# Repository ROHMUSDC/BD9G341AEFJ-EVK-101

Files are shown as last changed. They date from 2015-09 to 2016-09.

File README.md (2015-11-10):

# BD9G341AEFJ-EVK-101 Design Resource Repository
* Hardware Design Files and Documentation for the ROHM BD9G341AEFJ-EVK-101 EVK

----
### Description: 
* The BD9G341AEFJ is a buck switching regulator with integrated 150m Ω power MOSFET
* Current mode architecture provides fast transient response and a simple phase compensation setup
* The operating frequency is programmable from 50kHz to 750kHz
* Over current protection, thermal shutdown and under voltage lockout are also included with the IC
* The under voltage lockout and hysteresis can be set by external resistor

----
### Repository Contents
* Design Files: Contains Board, Gerber, Schematic, and BOM information for this EVK Board
* Measurement Reports Folder: Contains measurement testing information completed for these EVK Boards
* RoHS Compliance Folder: Contained RoHS Specific BOM and references to CoCs for parts on this board
* User's Guide: Contains the User Guide for this EVK

----
### Where to Purchase?
* http://www.rohm.com/web/global/distribution/-/dinventory/BD9G341AEFJ-E2/sample/0

----
### DISCLAIMER
This Technical Data is protected under copyright laws.

ROHM hereby grants you a nonexclusive, nontransferable license to use this Technical Data 
as long as you abide by the terms and conditions of this DISCLAIMER. 

However, you are not authorized to sell, loan, rent, lease, redistribute or license this Technical Data, 
in whole or in part, or in modified form, to anyone.

You may modify this Technical Data to suit your specific applications, 
but the rights to derivative works and said modifications shall belong to ROHM. 

You may make copies of this Technical Data as necessary for internal use only within your company.

In any case, the latest datasheet is considered the final design guideline and represents 
the only actual performance specifications.

ROHM shall not be responsible for ensuring proper application on all computer systems.
This Technical Data is provided AS IS. ROHM makes no guarantees, either implicitly or explicitly, 
regarding its usability, functionality, accuracy, merchantability, or fitness for a specific purpose.

In addition, you shall take full responsibility for the use of any information acquired from this Technical Data. 

ROHM does not assume warranty of any kind arising from the use of this Technical Data. ACCORDINGLY, 
IN NO EVENT SHALL ROHM BE RESPONSIBLE, WHETHER THROUGH CONTRACT OR TORT LIABILITY, 
FOR ANY DAMAGES (INCLUDING BUT NOT LIMITED TO LOST PROFITS OR OTHER INCIDENTAL, CONSEQUENTAL, 
OR PUNITIVE DAMAGES) ARISING OUT OF OR IN CONNECTION WITH THE USE OR APPLICATION OF THIS Technical Data.

Furthermore, this Technical Data is subject to change without notice.

Unless otherwise expressly provided herein, ROHM does not convey any license under patent rights 
or any other intellectual property rights (including those of third parties).

ROHM is not obligated to provide maintenance or support for the Technical Data.

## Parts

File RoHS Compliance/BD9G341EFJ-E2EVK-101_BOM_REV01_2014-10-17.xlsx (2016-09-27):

BD9G341EFJ-E2EVK-101 |  |  | FAB/ASSY RoHS Certificate of Compliance: |  | FAB-9_FAB-ASSY_RoHS Cert.pdf
Revision: 0.1
Bill Of Materials
Item | Quantity | Reference | Part | PCB Footprint | DESCRIPTION | MFG1 | MFG1_PART# | DISTR1 | DISTR1_PART# | DNP | Provided by ROHM | ROHM Comment
1 | 1 | C1 | 10uF | C2421 | CAP CER 10UF 100V 20% X7R SMD | Murata Electronics North America | KRM55TR72A106MH01K | Digi-Key | 490-5783-2-ND |  | Y | Murata_CO2E_100112-558472.pdf
2 | 1 | C3 | 6800pF | C0603 | CAP CER 6800PF 50V 10% X7R 0603 | Murata Electronics North America | GRM188R71H682KA01D | Digi-Key | 490-1508-2-ND |  | Y | Murata_CO2E_100112-558472.pdf
3 | 1 | C4 | 0.1uF | C0603 | CAP CER 0.1UF 50V 10% X7R 0603 | Murata Electronics North America | GRM188R71H104KA93D | Digi-Key | 490-1519-2-ND |  | Y | Murata_CO2E_100112-558472.pdf
4 | 1 | C5 | 100uF | C1206 | CAP CER 100UF 6.3V 20% X5R 1206 | Murata Electronics North America | GRM31CR60J107ME39L | Digi-Key | 490-4539-2-ND |  | Y | Murata_CO2E_100112-558472.pdf
5 | 1 | D2 | RB095B-90TL | SC-63 | DIODE SCHOTTKY 90V 3A CPD | Rohm | RB095B-90TL | Digi-Key | RB095B-90TLTR-ND |  | Y | RoHS Compliance Letter_20131212.pdf
6 | 1 | J1 | 68000-103HLF | HDR_THVT_1X3_100 | CONN HEADER VERT .100 3POS 15AU | FCI | 68000-103HLF | DIGIKEY | 609-3461-ND |  | N | FCICOC68000-103HLF.pdf
7 | 1 | L1 | 33uH | IND-4747-SMD | INDUCTOR POWER 33UH 4.2A SMD | Wurth Electronics Inc | 7447709330 | Digi-Key | 732-1244-2-ND |  | Y | WurthRoHS.pdf
8 | 1 | R1 | 110k | R0603 | RES 110K OHM 1/10W 1% 0603 SMD | Rohm | MCR03ERTF1103 | Digi-Key | RHM110KCFTR-ND |  | Y | RoHS Compliance Letter_20131212.pdf
9 | 1 | R2 | 27k | R0603 | RES 27K OHM 1/10W 1% 0603 SMD | Rohm | MCR03ERTF2702 | Digi-Key | RHM27.0KCFTR-ND |  | Y | RoHS Compliance Letter_20131212.pdf
10 | 1 | R3 | 10k | R0603 | RES 10K OHM 1/10W 1% 0603 SMD | Rohm | MCR03ERTF1002 | Digi-Key | RHM10.0KCFTR-ND |  | Y | RoHS Compliance Letter_20131212.pdf
11 | 1 | R4 | 47k | R0603 | RES 47K OHM 1/10W 1% 0603 SMD | Rohm | MCR03ERTF4702 | Digi-Key | RHM47.0KCFTR-ND |  | Y | RoHS Compliance Letter_20131212.pdf
12 | 1 | R5 | 3k | R0603 | RES 3K OHM 1/10W 1% 0603 SMD | Rohm | MCR03ERTF3001 | Digi-Key | RHM3.00KCFTR-ND |  | Y | RoHS Compliance Letter_20131212.pdf
13 | 1 | R6 | 750 | R0603 | RES 750 OHM 1/10W 1% 0603 SMD | Rohm | MCR03ERTF7500 | Digi-Key | RHM750CFTR-ND |  | Y | RoHS Compliance Letter_20131212.pdf
14 | 2 | TP1,TP3 | TP_TH_63MIL_RED | TP_TH | TEST POINT PC MULTI PURPOSE RED | Keystone Electronics | 5010 | Digi-Key | 5010K-ND |  | N | KeystoneRoHS.pdf
15 | 2 | TP2,TP4 | TP_TH_63MIL_BLK | TP_TH | TEST POINT PC MULTI PURPOSE BLK | Keystone Electronics | 5011 | Digi-Key | 5011K-ND |  | N | KeystoneRoHS.pdf
16 | 1 | U1 | BD9G341EFJ | HTSOP-J8 | IC REG BUCK SYNC ADJ 3A HTSOP-J8 |  |  |  |  |  | Y
17 | 1 |  |  |  | Shunt jumper for header J1(item #6), CONN SHUNT 2POS GOLD W/HANDLE | TE Connectivity | 881545-1 | Digi-Key | 881545-1-ND |  | N | TE_RoHS.pdf
18 | 2 | C2,C7 | TBD | C0603 |  |  |  |  |  | Do Not Place
19 | 1 | C6 | TBD | C1210 |  |  |  |  |  | Do Not Place
20 | 1 | D1 | TBD | DO-214AB |  |  |  |  |  | Do Not Place

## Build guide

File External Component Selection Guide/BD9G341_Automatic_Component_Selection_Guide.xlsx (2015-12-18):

How to Use this Selector Guide: 1. Fill in the constants that are highlighted yellow in column B 2. Change External components in Green Font to meet the optimized characteristics 3. Refer to User Manual and Schematic for any additional questions on why these values are set as they are.
Please refer to the schematic found in the GitHub Repository at the following location: ...BD9G341AEFJ-EVK-101/Design Files/Schematic_BOM/BD9G341EFJ-E2EVK-101_SCH_REV01_2014-10-17.pdf
Please refer to the user's guide found in the GitHub repository at the following location for explanation on the calculations completed in this document: ...BD9G341AEFJ-EVK-101/User's Guide/BD9G341AEFJ-EVK-101_EVK_UsersGuide_REV03_E_151027.pdf
BD9G341 Components Selection
Vcc (V) | 40
Vout (V) | 10
Inductor (uH) : L1 | 33
Switching Frequency (kHz) | 400
Output Ripple Current (mA) | 0.5681818182
Pull-up Feedback Resistor (kOhms) : R1 | 18
Pull-down feedback Resistor (kOhms) : R2 | 2
Cout (uF) | 100
ESR[Cout] (mOhms) | 0.1
Output Ripple Voltage (mV) | 2.317541805
Iout (mA) | 3000
Maximum Input Ripple Voltage (mV) | 50
CVCC (uF) : C1 | 10
Input Ripple Voltage (mV) | 140.625
Input Ripple Current (A) | 1.299038106
Maximum Input Ripple Current (A) | 1.5
Compensation Resistor (ohms) : R3 | 41887.90205
Compensation Capacitor (nF) : C3 > | 0.7599088773
Second Phase Compensation (uF) : C8 | 0
Under-voltage lockout threshold (V) | 9
UVLO Hysterisys (V) | 0.9
Enable Resistor Network (Pull-Up) (Kohms) : R5 | 90
Enable Resistor Network (Pull-Down) (Kohms) : R6 | 36.5625
Oscillation Resistance (kOhms) : R4 | 21.76616915
Maximum Duty Cycle | 0.8
Maximum output Voltage | 31.9325

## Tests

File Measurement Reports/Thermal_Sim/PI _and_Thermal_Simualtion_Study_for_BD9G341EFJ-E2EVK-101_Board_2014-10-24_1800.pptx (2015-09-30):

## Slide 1

PI and Thermal Simulation Study for BD9G341EFJ Board
October 24th, 2014
Hosted by: Xuan Dang/Chuong Ngo

PTH Solutions Confidential

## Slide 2

Agenda
  I. Introduction
  II. DC Drop Analysis
  III. Current Density Analysis
  IV. Thermal Analysis
  V. Conclusion

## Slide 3

Introduction

1. This work considers power simulation and thermal simulation on BD9G341EFJ boards.
  - Based on board file BD9G341EFJ-E2EVK-101_BRD_REV00_2014-10-17_1800.brd
2. PowerDC software is used for simulation
3. PI simulation considers:
  a. DC Drop analysis
    - Determine what the max drop for power rail
  b. Current Density analysis
    - Determine the hot spot of current density on PCB
4. Thermal simulation considers:
    - PCB temperature profile including consideration for conductive, radiative, and convective heat transfer

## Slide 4

BD9G341EFJ Board

- Based on the board file : BD9G341EFJ-E2EVK-101_BRD_REV00_2014-10-17_1800.brd

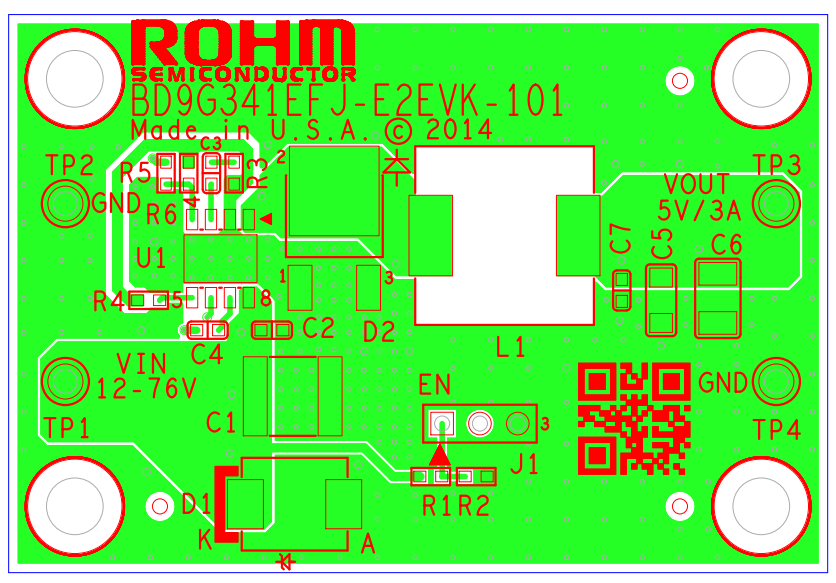
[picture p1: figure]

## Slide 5

BD9G341EFJ Schematic

Based on the schematic file : BD9G341EFJ-E2EVK-101_SCH_REV00_2014-10-17.pdf

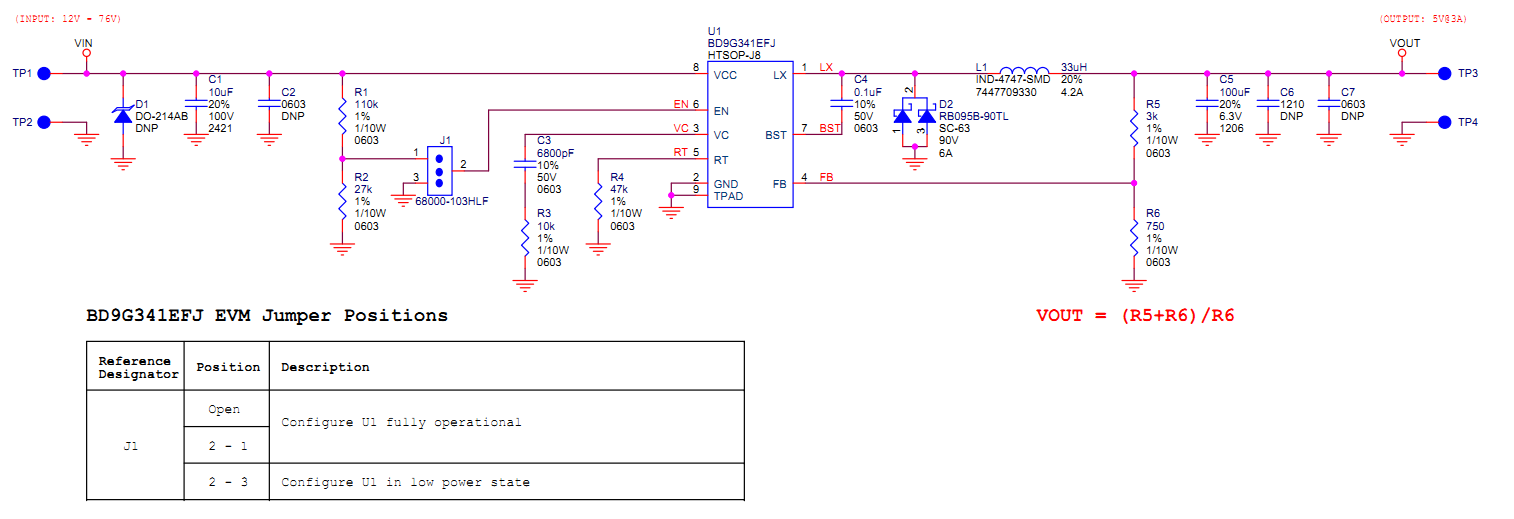
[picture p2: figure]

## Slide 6

BD9G341EFJ Board power consumption

Device/rail | Source/VRM refdes | Source PCB netname | Sink/load PCB refdes | Load PCB net name | Nominal Voltage(V) | Voltage tolerance (%) | Max current (A) | Power input (W) | Power consumption (W) | Note
Power input via TP1/TP2 connectors (VIN 12-76V) | TP1 | VIN | U1 | VIN | 12 | | 1.75 | 21 | | Max input current = (Pout + PONH + Psw + Pq + PL)/VIN = 1.34A with Vin= 12 V. So we choose max input current = 1.75A
| | | | | 76 | | 0.253 | 19.23 | | Per customer’s instruction, Efficiency is 78%.Max input current = Vout x Iout / Vin x ( 100 / Efficiency )= 0.253A with Vin= 76V. So we choose max input current = 0.253A
Power dissipation on BD9G341EFJ | TP1 | VIN | U1 | VIN | 12 | | 1.75 | | 0.702 | RONH = 0.15 Ohm , Fsw = 200KHz, Icc = 2 mA
| | | | | 76 | | 0.253 | | 3.825 | Pd= Pin –Pout-PL=76*0.253-5*3-0.405=3.825W
Power dissipation on inductor L1 | U1 | LX | L1 | LX | | | 3 | | 0.405 | RL = 0.045 Ohm
Power consumption at load via connector TP3/TP4 (VOUT 5V) | L1 | LX | TP3 | VOUT | 5 | 2 | 3 | | 15

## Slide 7

DC Drop analysis for VIN 12V@1.75A at TOP Layer

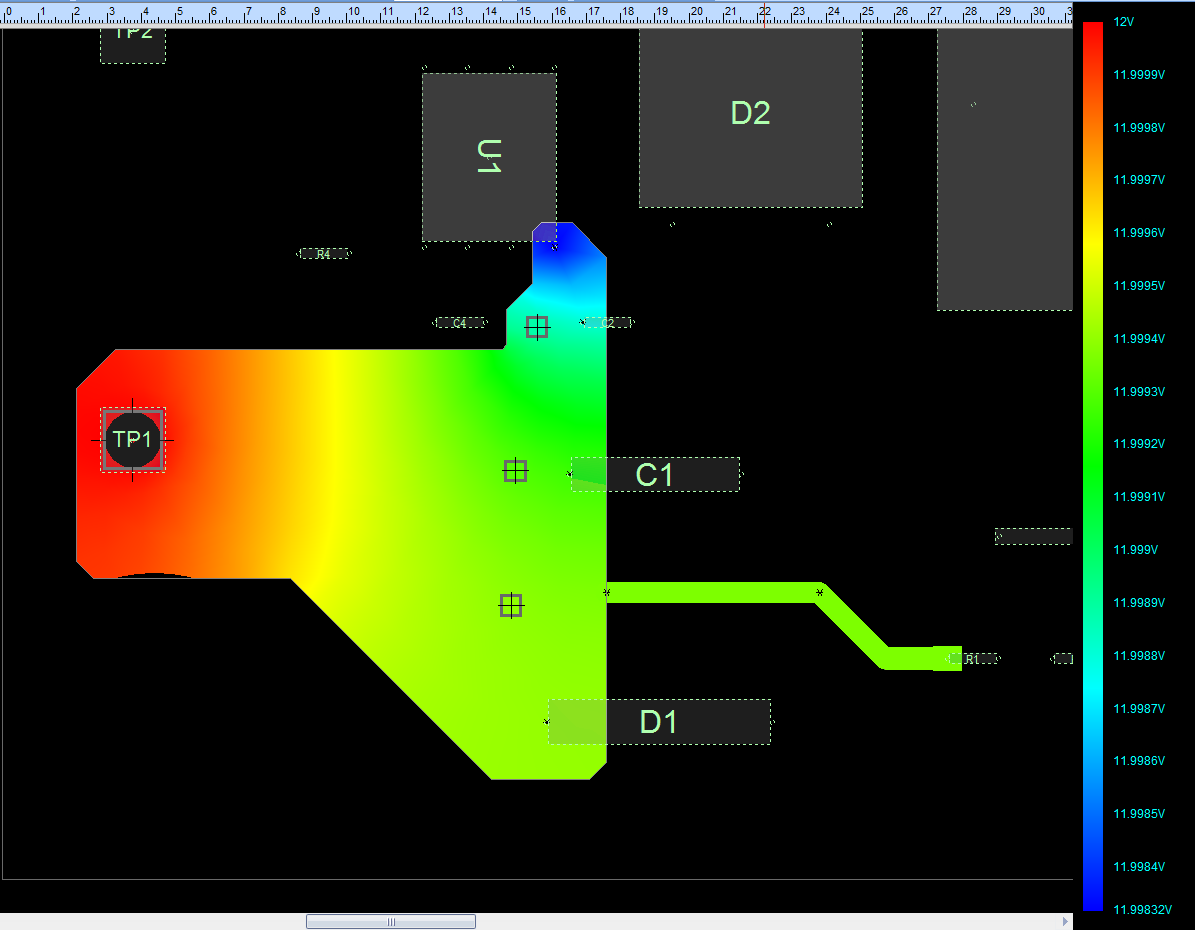
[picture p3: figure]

Max DC Drop 1.68mV < 240mV (2% tolerance of 12V) → Copper planes for VIN is OK

PTH Solutions Confidential

Load U1

Source TP1

10/24/2014

7

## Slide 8

DC Drop analysis for VIN 76V@0.253A at TOP Layer

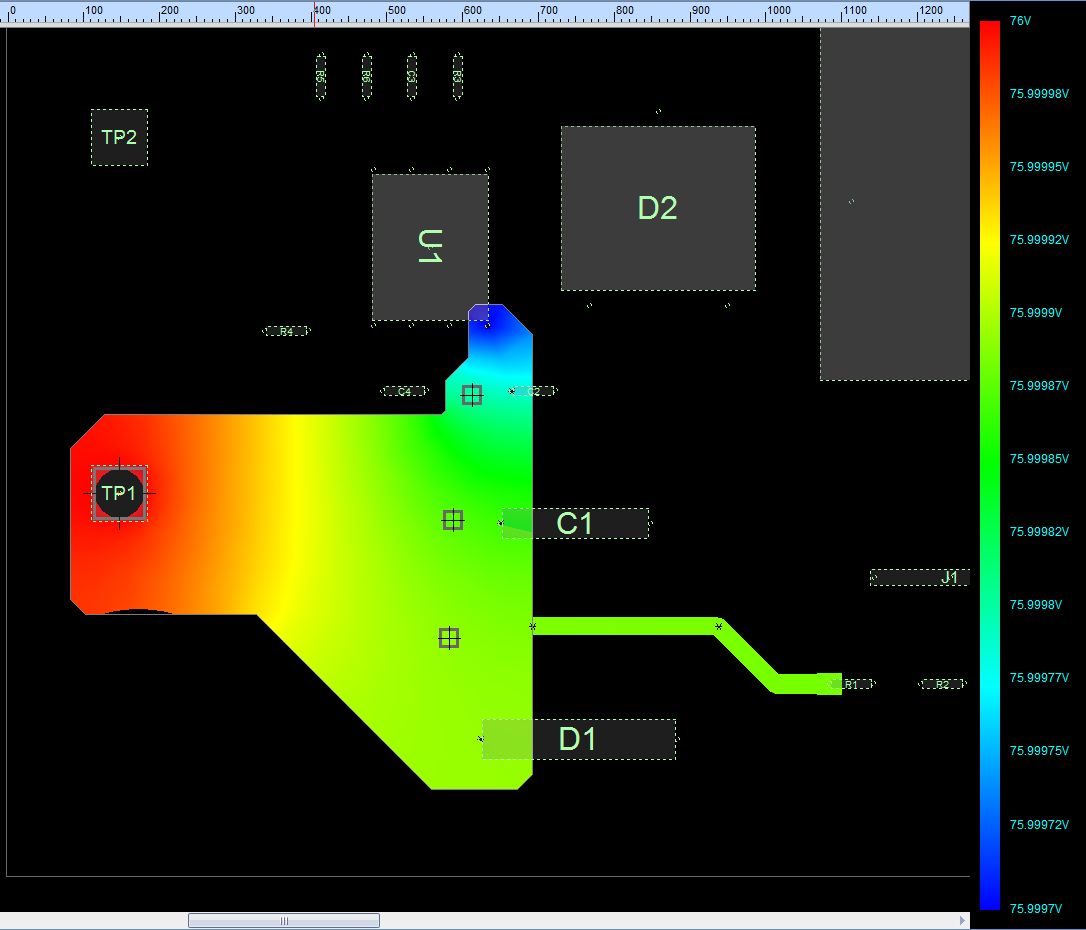
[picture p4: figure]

Max DC Drop 0.3mV < 1520mV (2% tolerance of 76V) → Copper planes for VIN is OK

Load U1

Source TP1

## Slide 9

Current Density analysis for VIN 12V@1.75A at TOP Layer

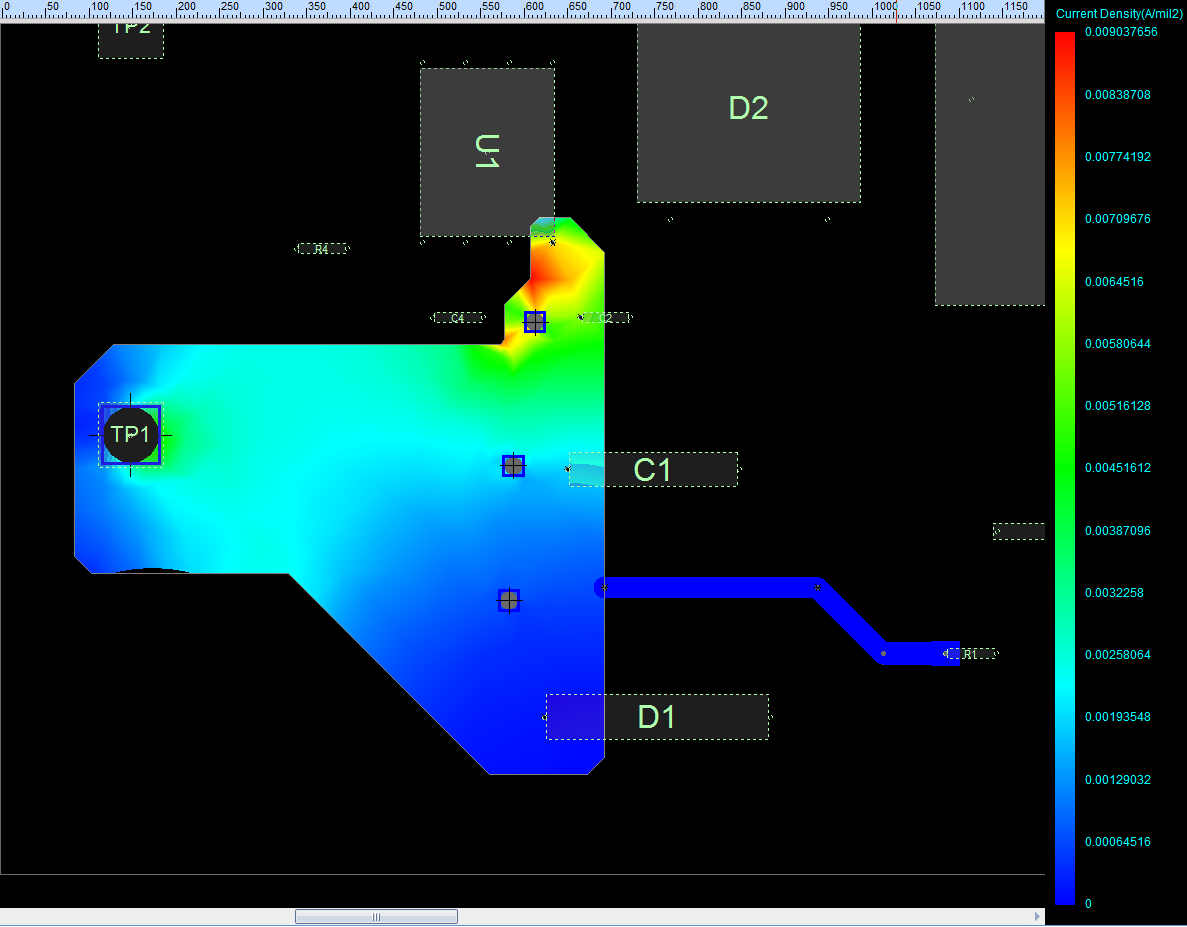
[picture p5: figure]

PTH Solutions Confidential

Load U1

Source TP1

Max Current Density 9.04mA/mil²<40mA/mil² (This rule limit 10 Celsius degree of temperature rise above ambient) → Copper plane for VIN is OK

10/24/2014

9

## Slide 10

Current Density analysis for VIN 76V@0.253A at TOP Layer

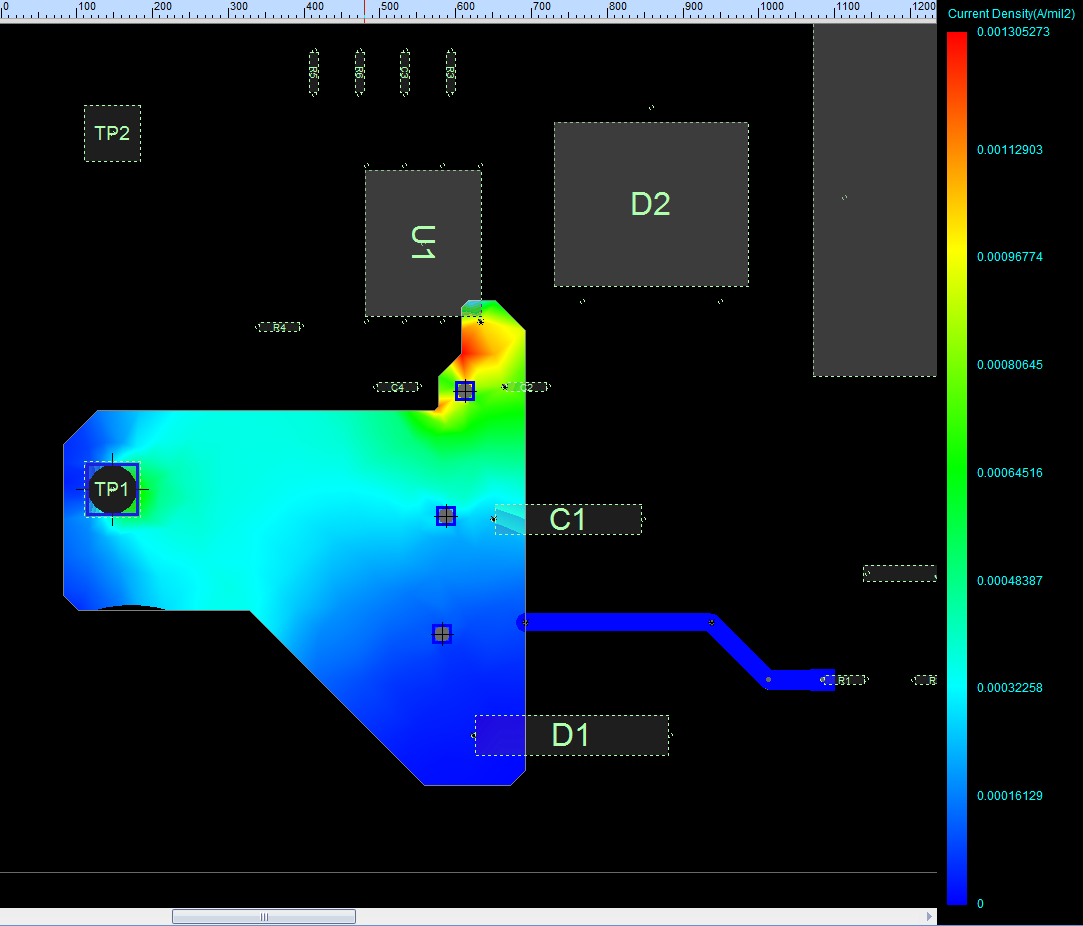
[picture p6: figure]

Load U1

Source TP1

Max Current Density 1.31mA/mil²<40mA/mil² (This rule limit 10 Celsius degree of temperature rise above ambient) → Copper plane for VIN is OK

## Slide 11

DC Drop analysis for VOUT 5V@3A at TOP layer (with Vin=12V)

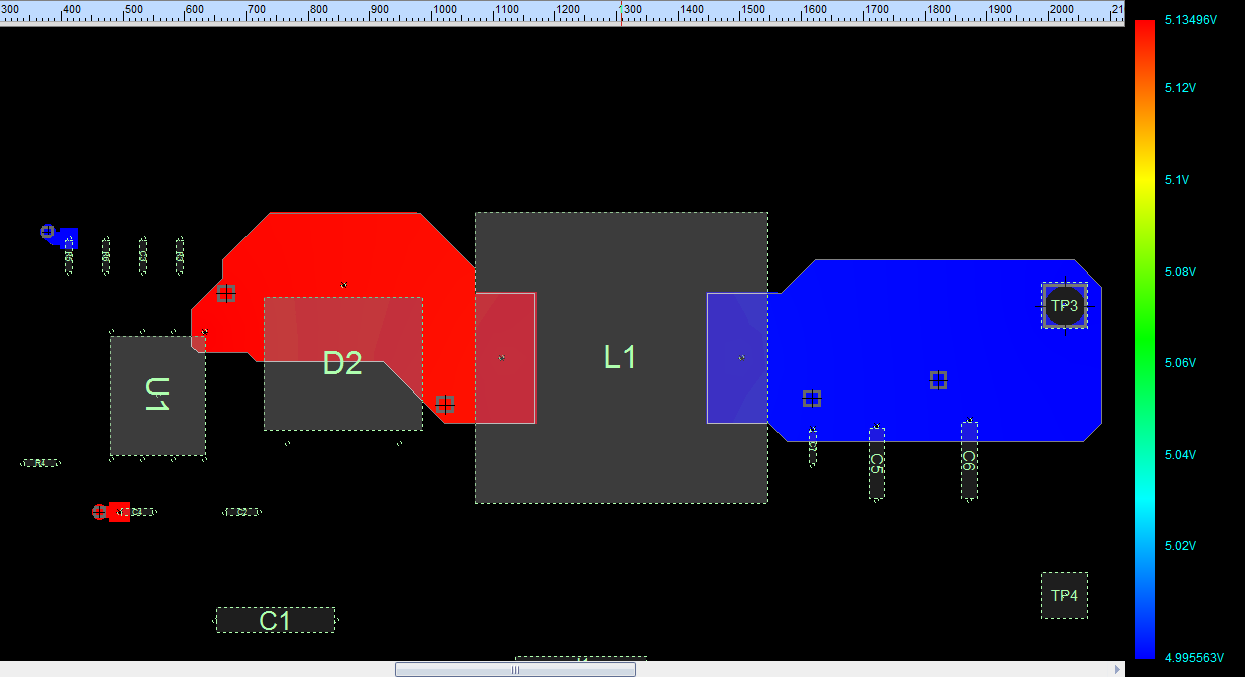
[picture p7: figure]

Max DC Drop 4.44mV < 100mV (2% tolerance of 5V) → Copper planes for VOUT is OK

Load TP3

Source L1

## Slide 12

DC Drop analysis for VOUT 5V@3A at TOP layer (with Vin=76V)

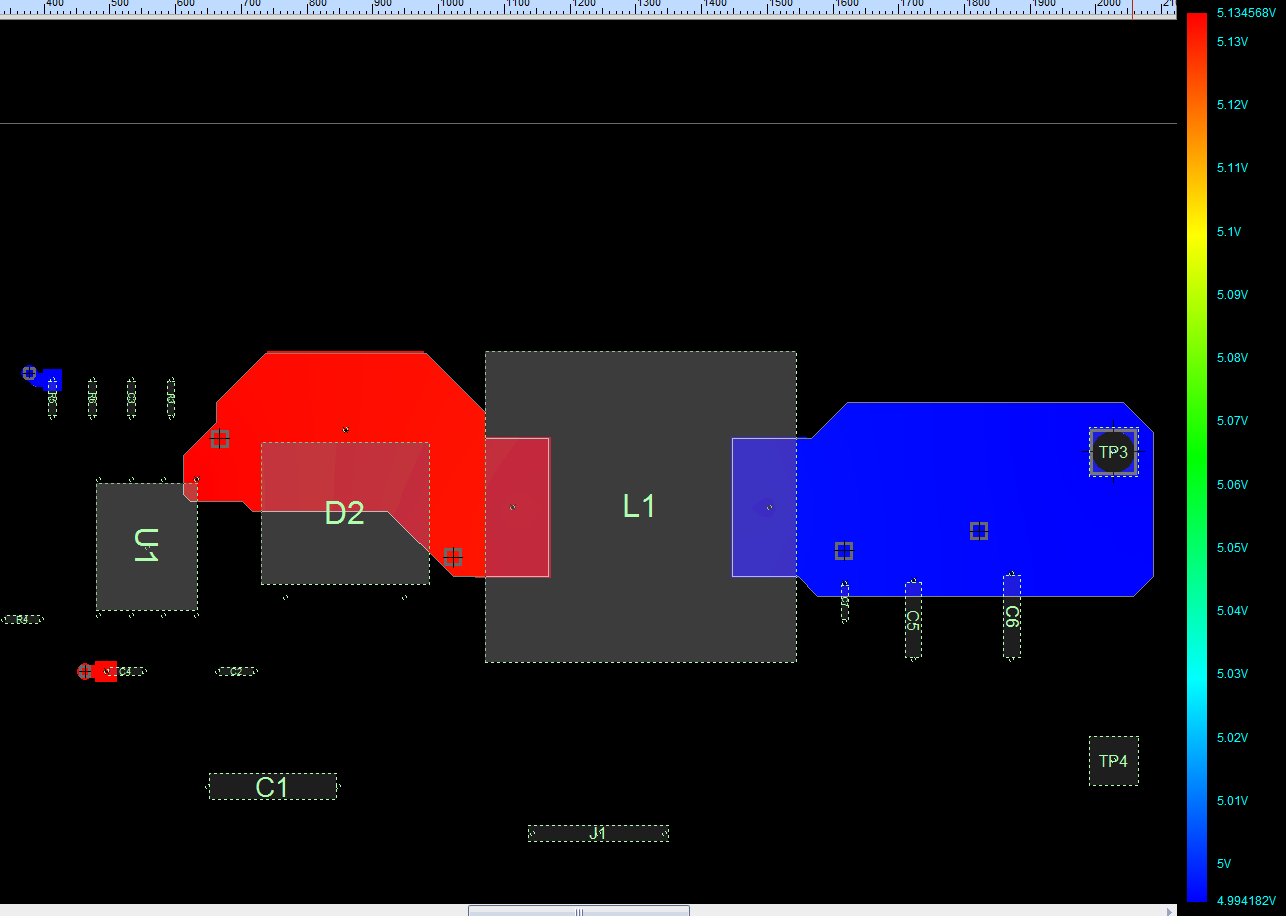
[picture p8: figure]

Max DC Drop 5.82mV < 100mV (2% tolerance of 5V) → Copper planes for VOUT is OK

PTH Solutions Confidential

Load TP3

Source L1

10/24/2014

12

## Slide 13

Current Density analysis for VOUT 5V@3A at TOP layer (with Vin=12V)

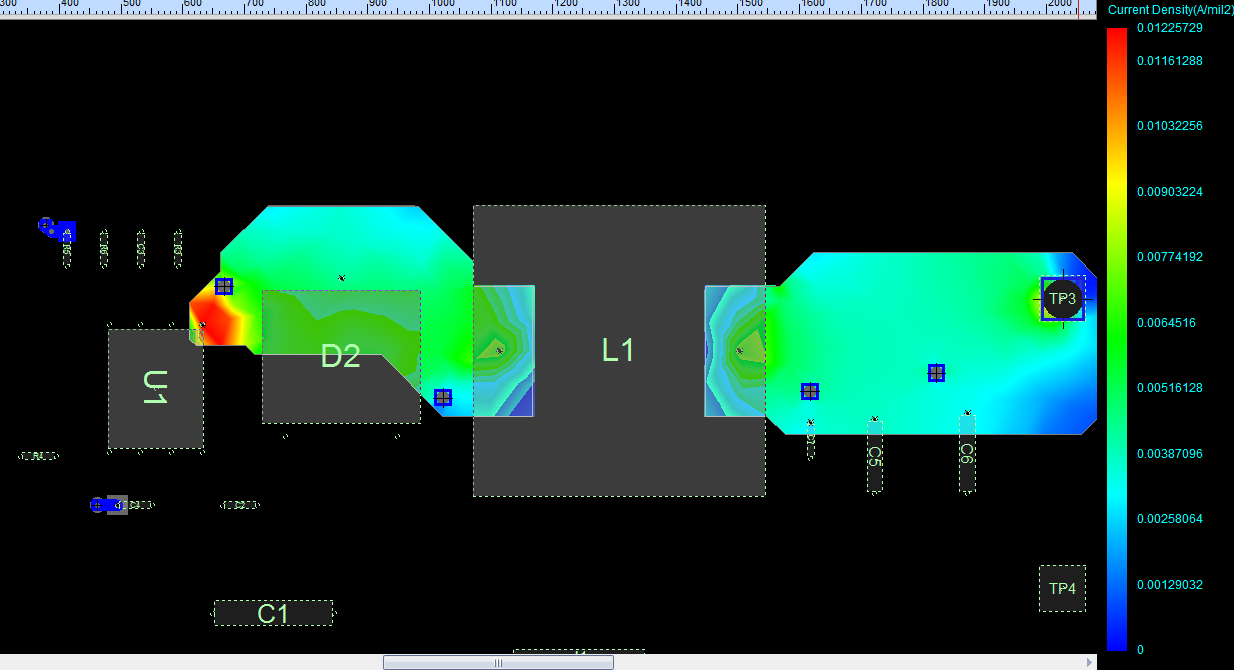
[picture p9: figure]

Max Current Density 12.26mA/mil²<40mA/mil² (This rule limit 10 Celsius degree of temperature rise above ambient) → Copper plane for VIN is OK

Load TP3

Source L1

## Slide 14

Current Density analysis for VOUT 5V@3A at TOP layer (with Vin=76V)

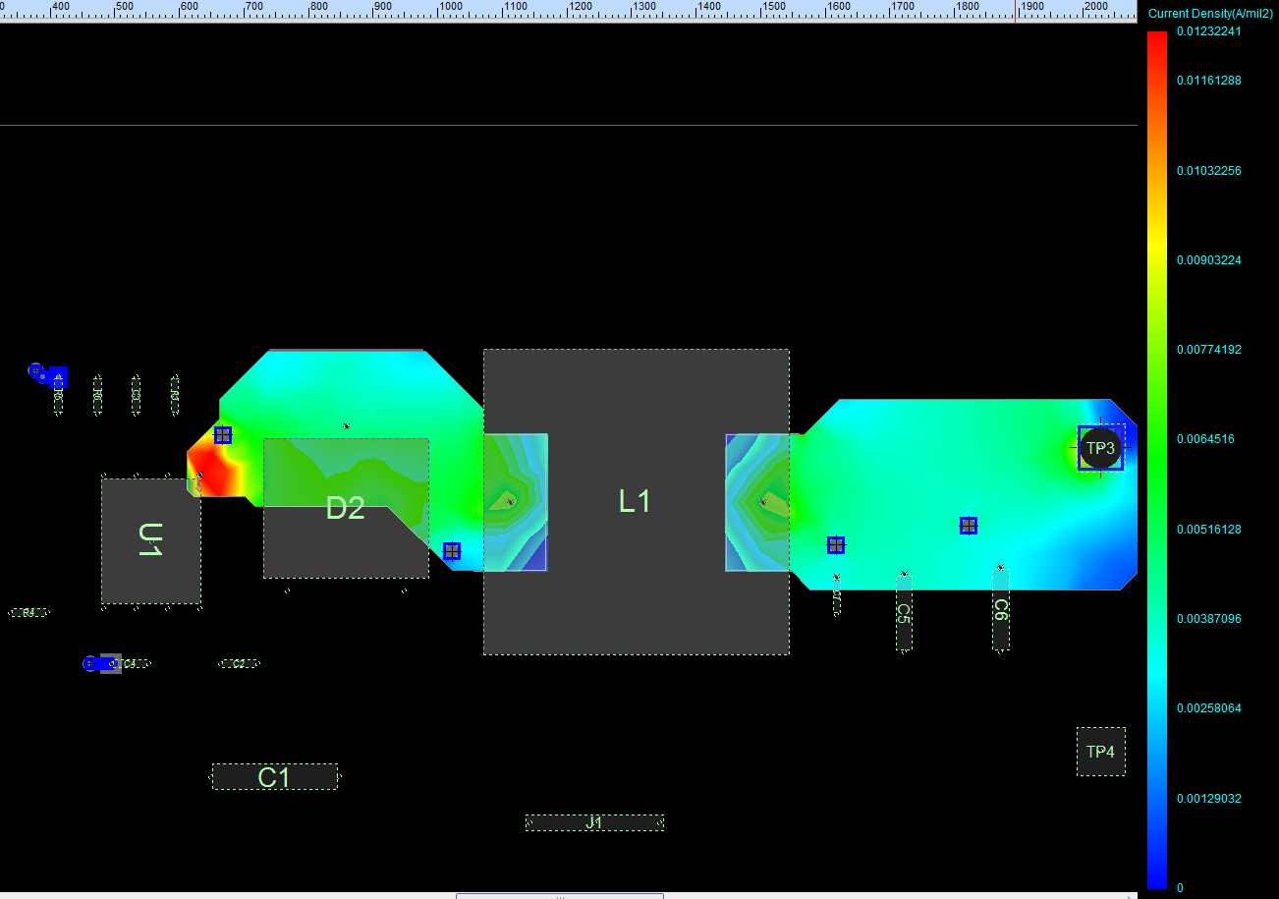
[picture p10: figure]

Max Current Density 12.32mA/mil²<40mA/mil² (This rule limit 10 Celsius degree of temperature rise above ambient) → Copper plane for VIN is OK

Load TP3

Source L1

14

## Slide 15

Thermal Analysis

a. Environment conditions
  a. Air Temperature : 25 ⁰C , 35 ⁰C and 45 ⁰C
  b. No incoming air flow (Natural convection)

VOUT 20mV/div (AC)

SW 5V/div

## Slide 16

Thermal Analysis (Con’t)

b. Component properties

| BD9G3441EFJ (U1) | 7447709330 (L1)
Number of pins | 9 | 2
Max. power dissipation | 0.702W at VIN=12V 3.825W at Vin=76V | 0.405W

VOUT 20mV/div (AC)

SW 5V/div

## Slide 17

Thermal Analysis (Con’t)

Air temperature 25⁰C, power dissipation of BD9G341EFJ is 0.702W (at VIN=12V, board size : 55x37.47mm)


The highest temperature on board is about 49.85 ⁰C
The highest temperature on component is on BD9G341EFJ( about 49.85 ⁰C)

U1: BD9G341EFJ
- Max. power dissipation: 0.702W @VIN=12V
- Component temperature = 49.85 ⁰C

L1: 7447709330
- Max. power dissipation: 0.405W
- Component temperature = 46.8 ⁰C

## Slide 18

Thermal Analysis (Con’t)

Air temperature 25⁰C, power dissipation of BD9G341EFJ is 3.825W (at VIN=76V, board size : 55x37.47mm)


The highest temperature on board is about 131.81 ⁰C
The highest temperature on component is on BD9G341EFJ( about 131.81 ⁰C)

U1: BD9G341EFJ
- Max. power dissipation: 3.825W @VIN=76V
- Component temperature = 131.81 ⁰C

L1: 7447709330
- Max. power dissipation: 0.405W
- Component temperature = 110.2 ⁰C

18

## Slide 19

Thermal Analysis (Con’t)

Air temperature 35⁰C, power dissipation of BD9G341EFJ is 0.702W (at VIN=12V, board size : 55x37.47mm)


The highest temperature on board is about 59.97 ⁰C
The highest temperature on component is on BD9G341EFJ ( about 59.97 ⁰C)

U1: BD9G341EFJ
- Max. power dissipation: 0.702W @VIN=12V
- Component temperature = 59.97 ⁰C

L1: 7447709330
- Max. power dissipation: 0.405W
- Component temperature = 57.48 ⁰C

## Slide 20

Thermal Analysis (Con’t)

Air temperature 35⁰C, power dissipation of BD9G341EFJ is 3.825W (at VIN=76V, board size : 55x37.47mm)


The highest temperature on board is about 142.47 ⁰C
The highest temperature on component is on BD9G341EFJ ( about 142.47 ⁰C)

U1: BD9G341EFJ
- Max. power dissipation: 3.825W @VIN=76V
- Component temperature = 142.47 ⁰C

L1: 7447709330
- Max. power dissipation: 0.405W
- Component temperature = 121.02 ⁰C

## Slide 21

Thermal Analysis (Con’t)

Air temperature 45⁰C, power dissipation of BD9G341EFJ is 0.702W (at VIN=12V, board size : 55x37.47mm)


The highest temperature on board is about 70.14 ⁰C
The highest temperature on component is on BD9G341EFJ ( about 70.14 ⁰C)

U1: BD9G341EFJ
- Max. power dissipation: 0.702W @VIN=12V
- Component temperature = 70.14 ⁰C

L1: 7447709330
- Max. power dissipation: 0.405W
- Component temperature = 67.56 ⁰C

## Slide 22

Thermal Analysis (Con’t)

Air temperature 45⁰C, power dissipation of BD9G341EFJ is 3.825W (at VIN=76V, board size : 55x37.47mm)


The highest temperature on board is about 153.1 ⁰C
The highest temperature on component is on BD9G341EFJ ( about 153.1 ⁰C)

U1: BD9G341EFJ
- Max. power dissipation: 3.825W @VIN=76V
- Component temperature = 153.1 ⁰C

L1: 7447709330
- Max. power dissipation: 0.405W
- Component temperature = 131.7 ⁰C

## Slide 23

Thermal Analysis (Con’t)

Air temperature 25⁰C, power dissipation of BD9G341EFJ is 3.825W (at VIN=76V, board size : 70x70mm)


U1: BD9G341EFJ
- Max. power dissipation: 3.825W @VIN=76V
- Component temperature = 86.2 ⁰C

L1: 7447709330
- Max. power dissipation: 0.405W
- Component temperature = 70.4 ⁰C

The highest temperature on board is about 86.2 ⁰C
The highest temperature on component is on BD9G341EFJ ( about 86.2 ⁰C)

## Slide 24

Thermal Analysis (Con’t)

Air temperature 35⁰C, power dissipation of BD9G341EFJ is 3.825W (at VIN=76V, board size : 70x70mm)


U1: BD9G341EFJ
- Max. power dissipation: 3.825W @VIN=76V
- Component temperature = 96.6 ⁰C

L1: 7447709330
- Max. power dissipation: 0.405W
- Component temperature = 80.8 ⁰C

The highest temperature on board is about 96.6 ⁰C
The highest temperature on component is on BD9G341EFJ ( about 96.6 ⁰C)

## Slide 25

Thermal Analysis (Con’t)

Air temperature 35⁰C, power dissipation of BD9G341EFJ is 3.825W (at VIN=76V, board size : 70x70mm)


U1: BD9G341EFJ
- Max. power dissipation: 3.825W @VIN=76V
- Component temperature = 106.9 ⁰C

L1: 7447709330
- Max. power dissipation: 0.405W
- Component temperature = 91.1 ⁰C

The highest temperature on board is about 106.9 ⁰C
The highest temperature on component is on BD9G341EFJ ( about 106.9 ⁰C)

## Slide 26

Summary

1. - With VIN=12V:the PI simulation shows that the max. amount voltage drop of VIN power is 1.68mV, the max. current density of VIN power is 9.04mA/mil²; the max. amount voltage drop of VOUT power is 4.44mV, the max. current density of VOUT power is 12.26mA/mil².
- With VIN=76V:the PI simulation shows that the max. amount voltage drop of VIN power is 0.3mV, the max. current density of VIN power is 1.03mA/mil²; the max. amount voltage drop of VOUT power is 5.82mV, the max. current density of VOUT power is 12.32mA/mil².
2. The highest temperature of BD9G341EFJ-E2EVK-101 board can be reached temperature as table below:

| Board Size: 55x37.47mm | | Board Size: 70x70mm
| VIN=12V | VIN=76V | VIN=76V
Air temperature: 25⁰C | 49.85 ⁰C | 131.81 ⁰C | 86.2 ⁰C
Air temperature: 35⁰C | 59.97 ⁰C | 142.47 ⁰C | 96.6 ⁰C
Air temperature: 45⁰C | 70.14 ⁰C | 153.1 ⁰C | 106.9 ⁰C

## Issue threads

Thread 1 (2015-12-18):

How do I optimize the external components on this board to change the output voltage and frequency of this DCDC?

kbahar, 2015-12-18:

satomi0223, 2015-12-18:
Please refer to the folder named "External Component Selection Guide".
There you will find an excel sheet where you can put your conditions and automatically find the external components required to meet the conditions.

Closed 2016-08-24.

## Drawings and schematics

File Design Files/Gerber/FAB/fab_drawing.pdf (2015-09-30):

D

2

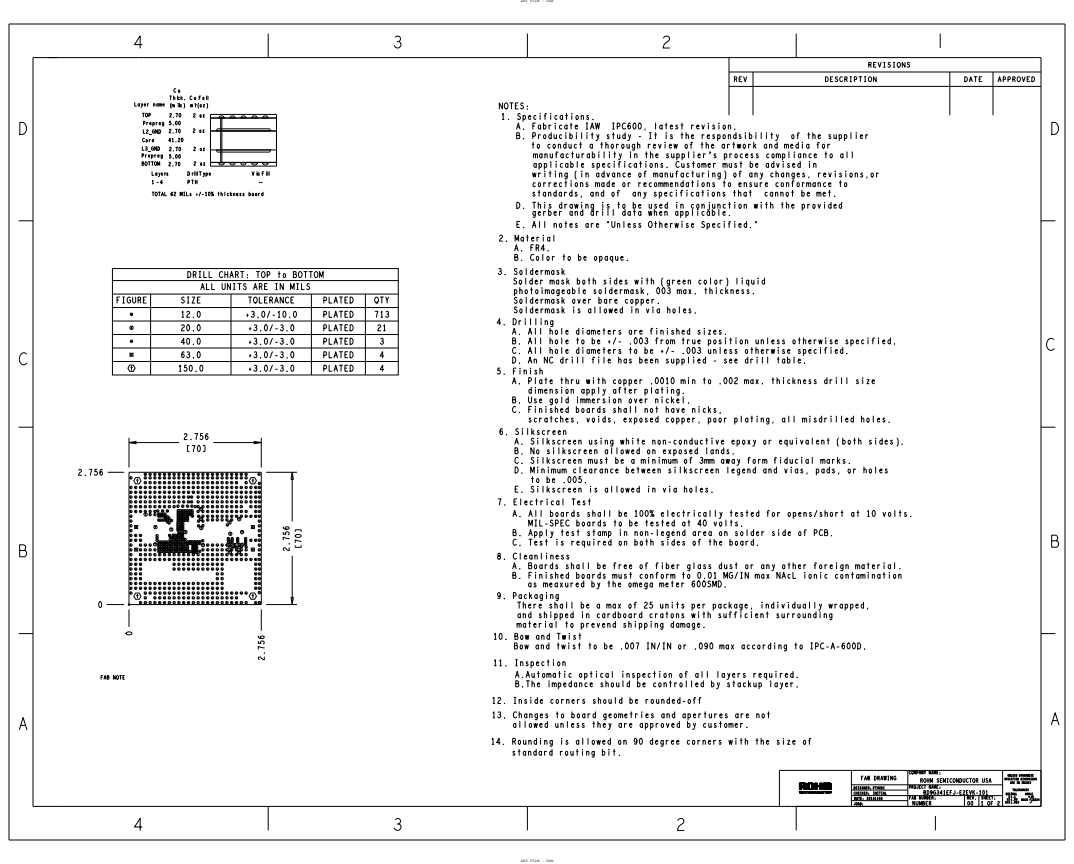
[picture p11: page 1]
SHEET:; REV. 00; FAB NUMBER: NUMBER; INITIAL; FAB DRAWING; DATE:; CHECKER:; JOB#:; applicable specifications. Customer; must; advised; standards, and of any specifications; that cannot; met.; A. Fabricate IAW IPC600,; latest; revision.; B. Producibility study -; the; respondsibility of; the supplier; corrections; made or; recommendations; to ensure conformance; D. This drawing is; be used; in conjunction with; provided; E. All; notes are "Unless Otherwise Specified."; A.Automatic optical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

ART FILM - FAB

REVISIONS

REV | DESCRIPTION | DATE | APPROVED

NOTES:
1. Specifications.
gerber and drill data when applicable.
2. Material
3. Soldermask
4. Drilling
5. Finish
C. Finished boards shall not have nicks,
scratches, voids, exposed copper, poor plating, all misdrilled holes.
6. Silkscreen
7. Electrical Test
A. All boards shall be 100% electrically tested for opens/short at 10 volts.
MIL-SPEC boards to be tested at 40 volts.
B. Apply test stamp in non-legend area on solder side of PCB.
C. Test is required on both sides of the board.
8. Cleanliness
A. Boards shall be free of fiber glass dust or any other foreign material.
B. Finished boards must conform to 0.01 MG/IN max NAcL ionic contamination
as meaxured by the omega meter 600SMD.
9. Packaging
and shipped in cardboard cratons with sufficient surrounding
10. Bow and Twist
Bow and twist to be .007 IN/IN or .090 max according to IPC-A-600D.
11. Inspection
12. Inside corners should be rounded-off
13. Changes to board geometries and apertures are not
allowed unless they are approved by customer.
14. Rounding is allowed on 90 degree corners with the size of
standard routing bit.

BOTTOM
TOTAL 62 MILs +/-10% thickness board

COMPANY NAME: ROHM SEMICONDUCTOR USA | UNLESS OTHERWISE SPECIFIED DIMENSIONS ARE IN INCHES TOLERANCES DECIMAL X ANGLE .1 30 MACH FINISH XX .03 XXX .010

DESIGNER: PTHVDC | PROJECT NAME: | BD9G341EFJ-E2EVK-101

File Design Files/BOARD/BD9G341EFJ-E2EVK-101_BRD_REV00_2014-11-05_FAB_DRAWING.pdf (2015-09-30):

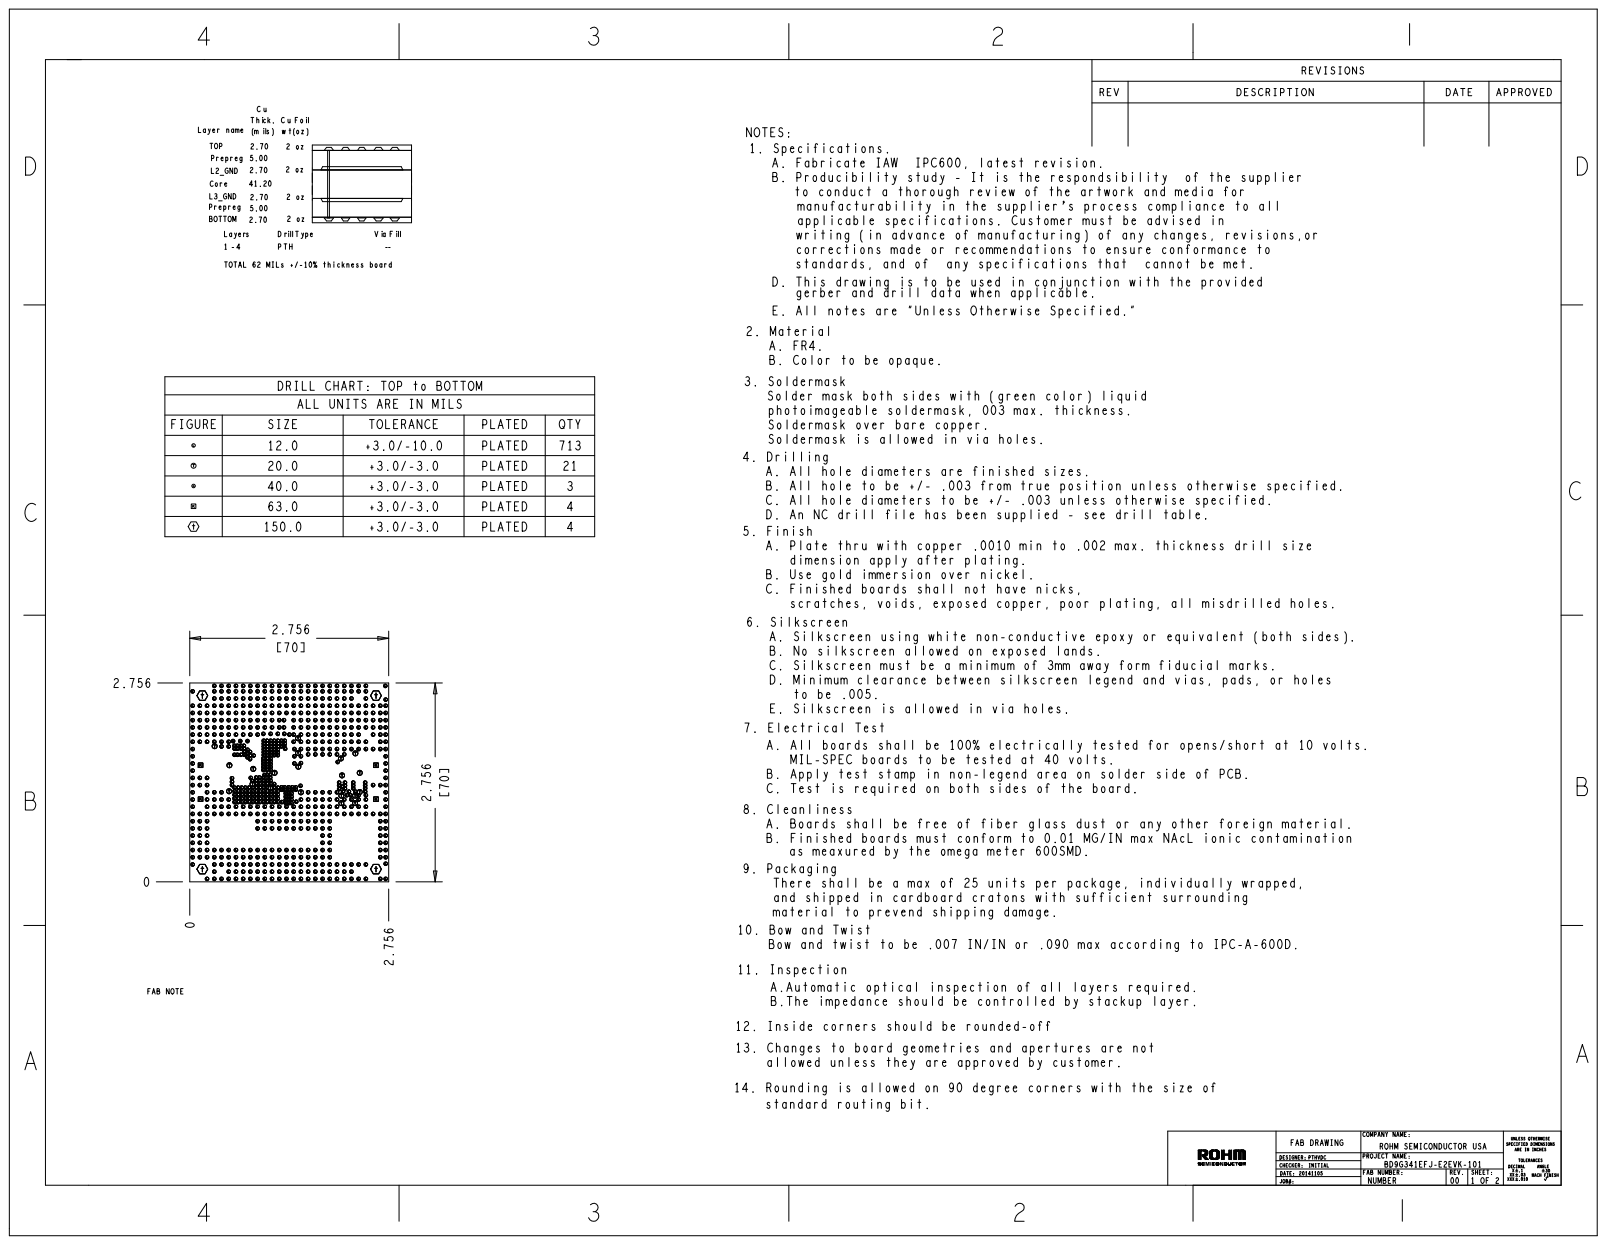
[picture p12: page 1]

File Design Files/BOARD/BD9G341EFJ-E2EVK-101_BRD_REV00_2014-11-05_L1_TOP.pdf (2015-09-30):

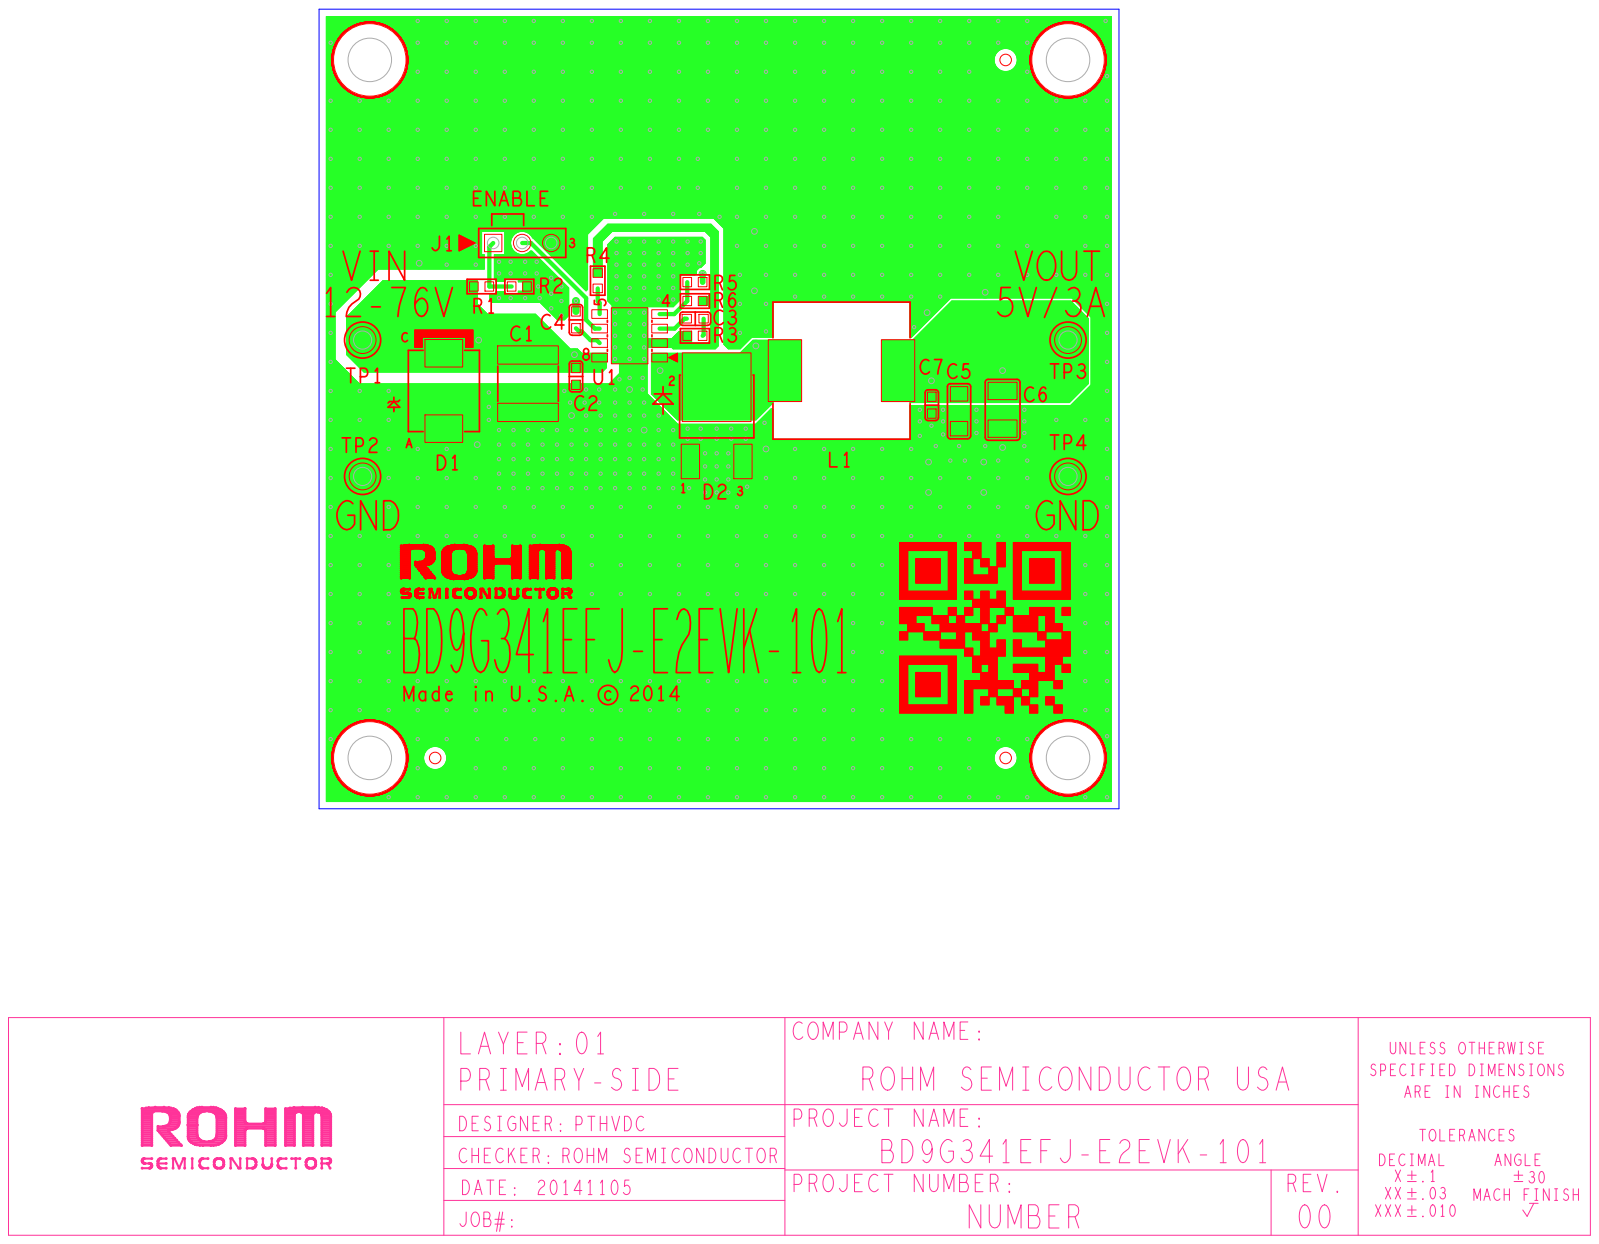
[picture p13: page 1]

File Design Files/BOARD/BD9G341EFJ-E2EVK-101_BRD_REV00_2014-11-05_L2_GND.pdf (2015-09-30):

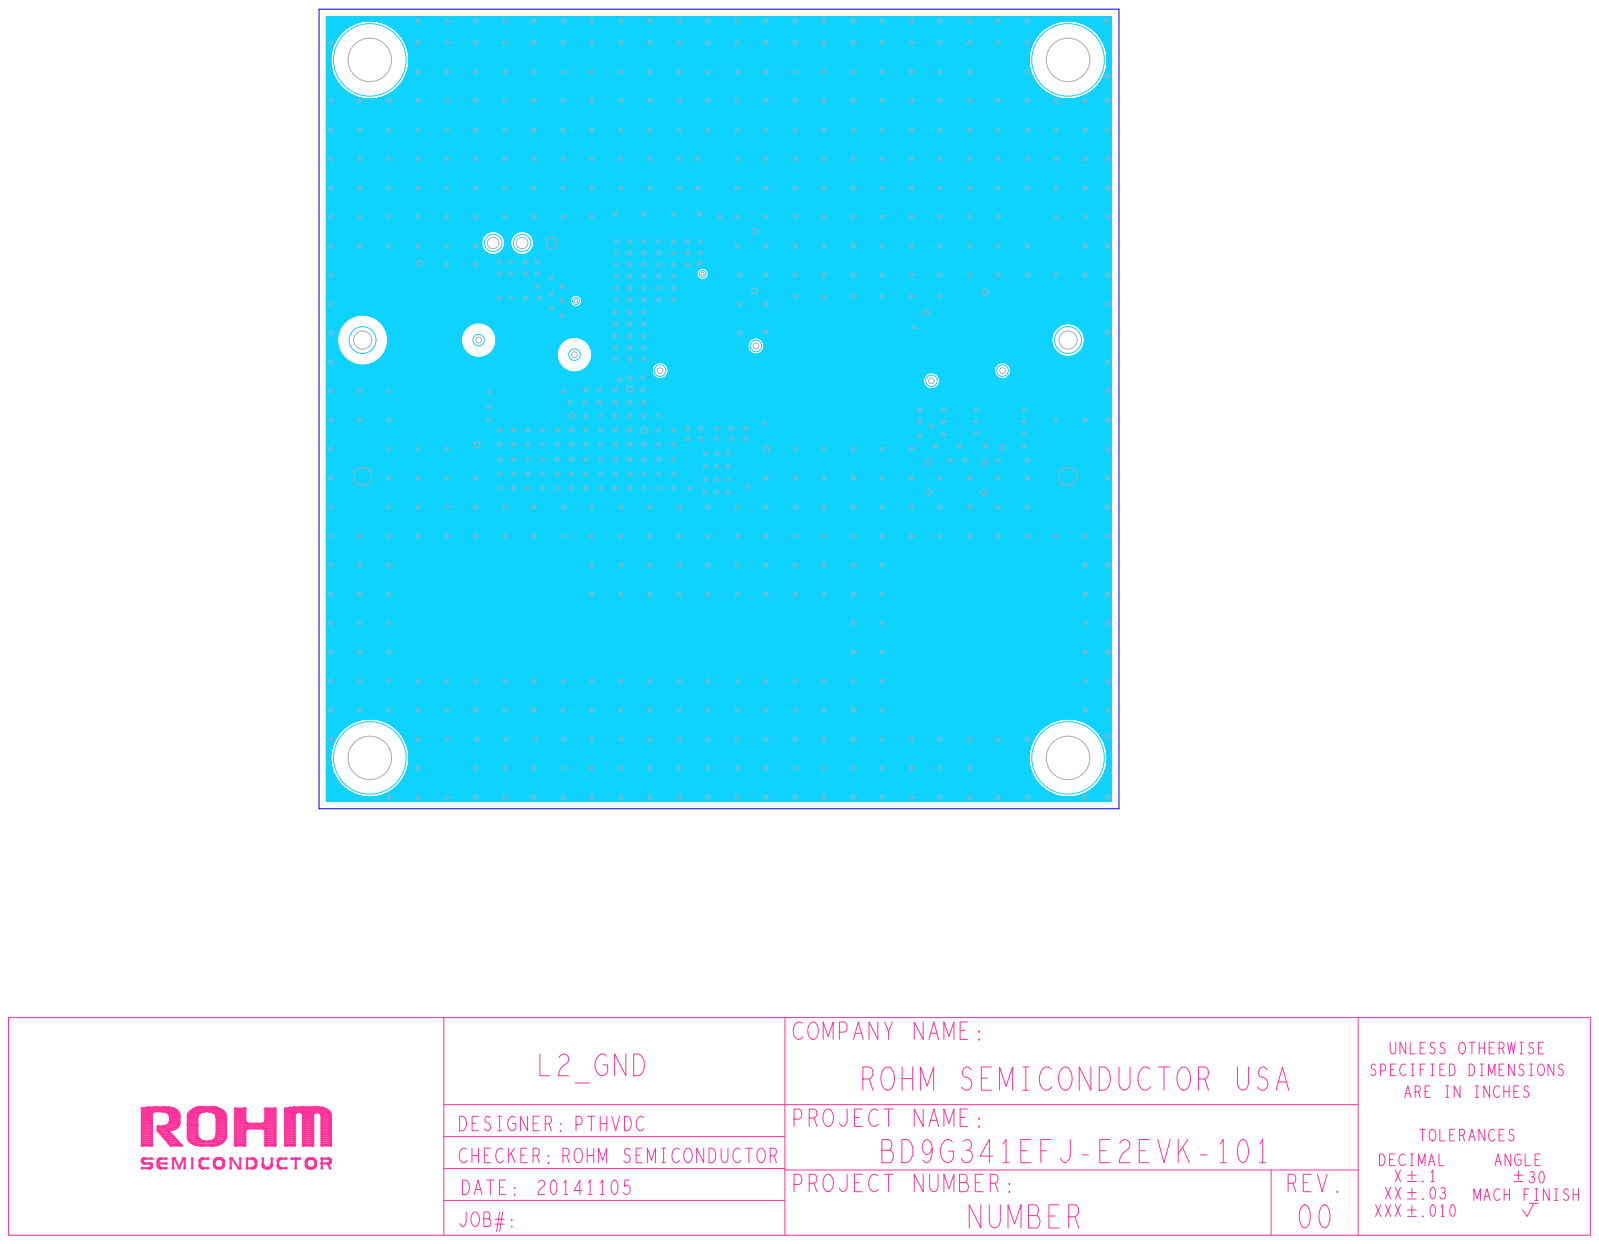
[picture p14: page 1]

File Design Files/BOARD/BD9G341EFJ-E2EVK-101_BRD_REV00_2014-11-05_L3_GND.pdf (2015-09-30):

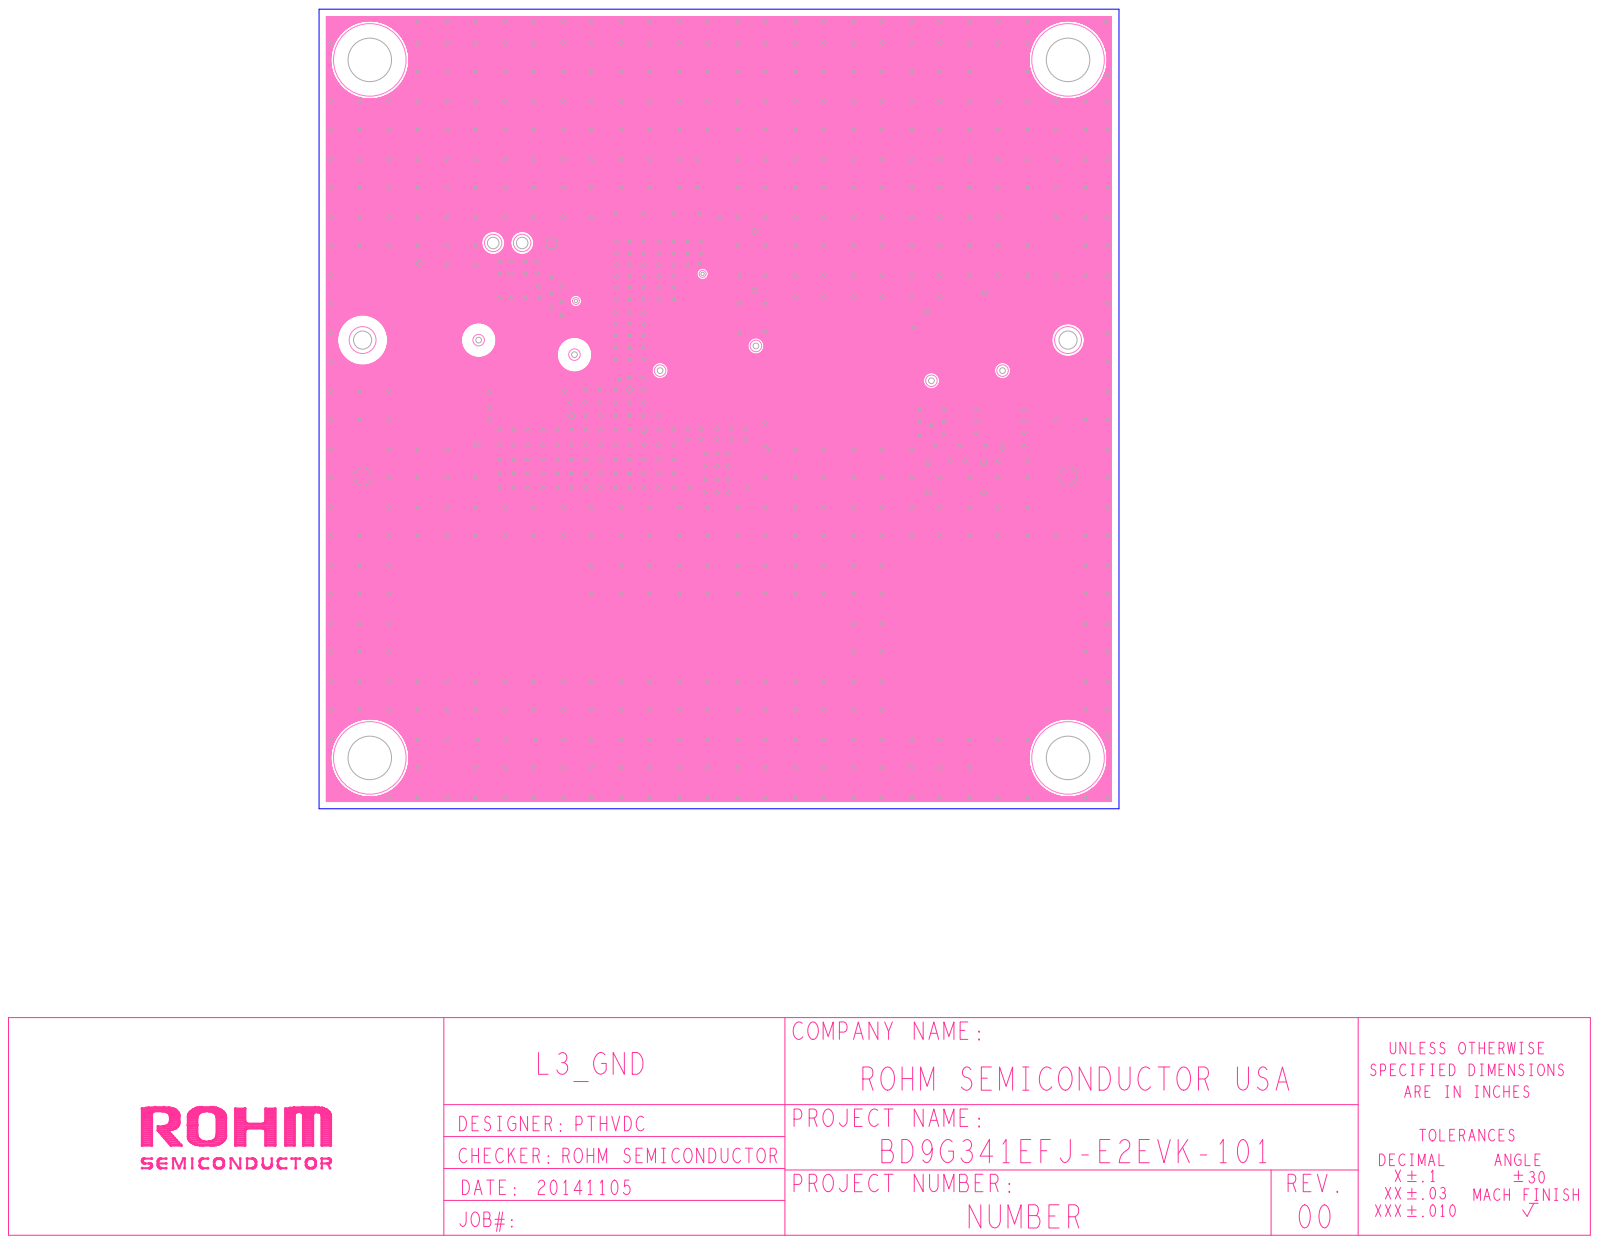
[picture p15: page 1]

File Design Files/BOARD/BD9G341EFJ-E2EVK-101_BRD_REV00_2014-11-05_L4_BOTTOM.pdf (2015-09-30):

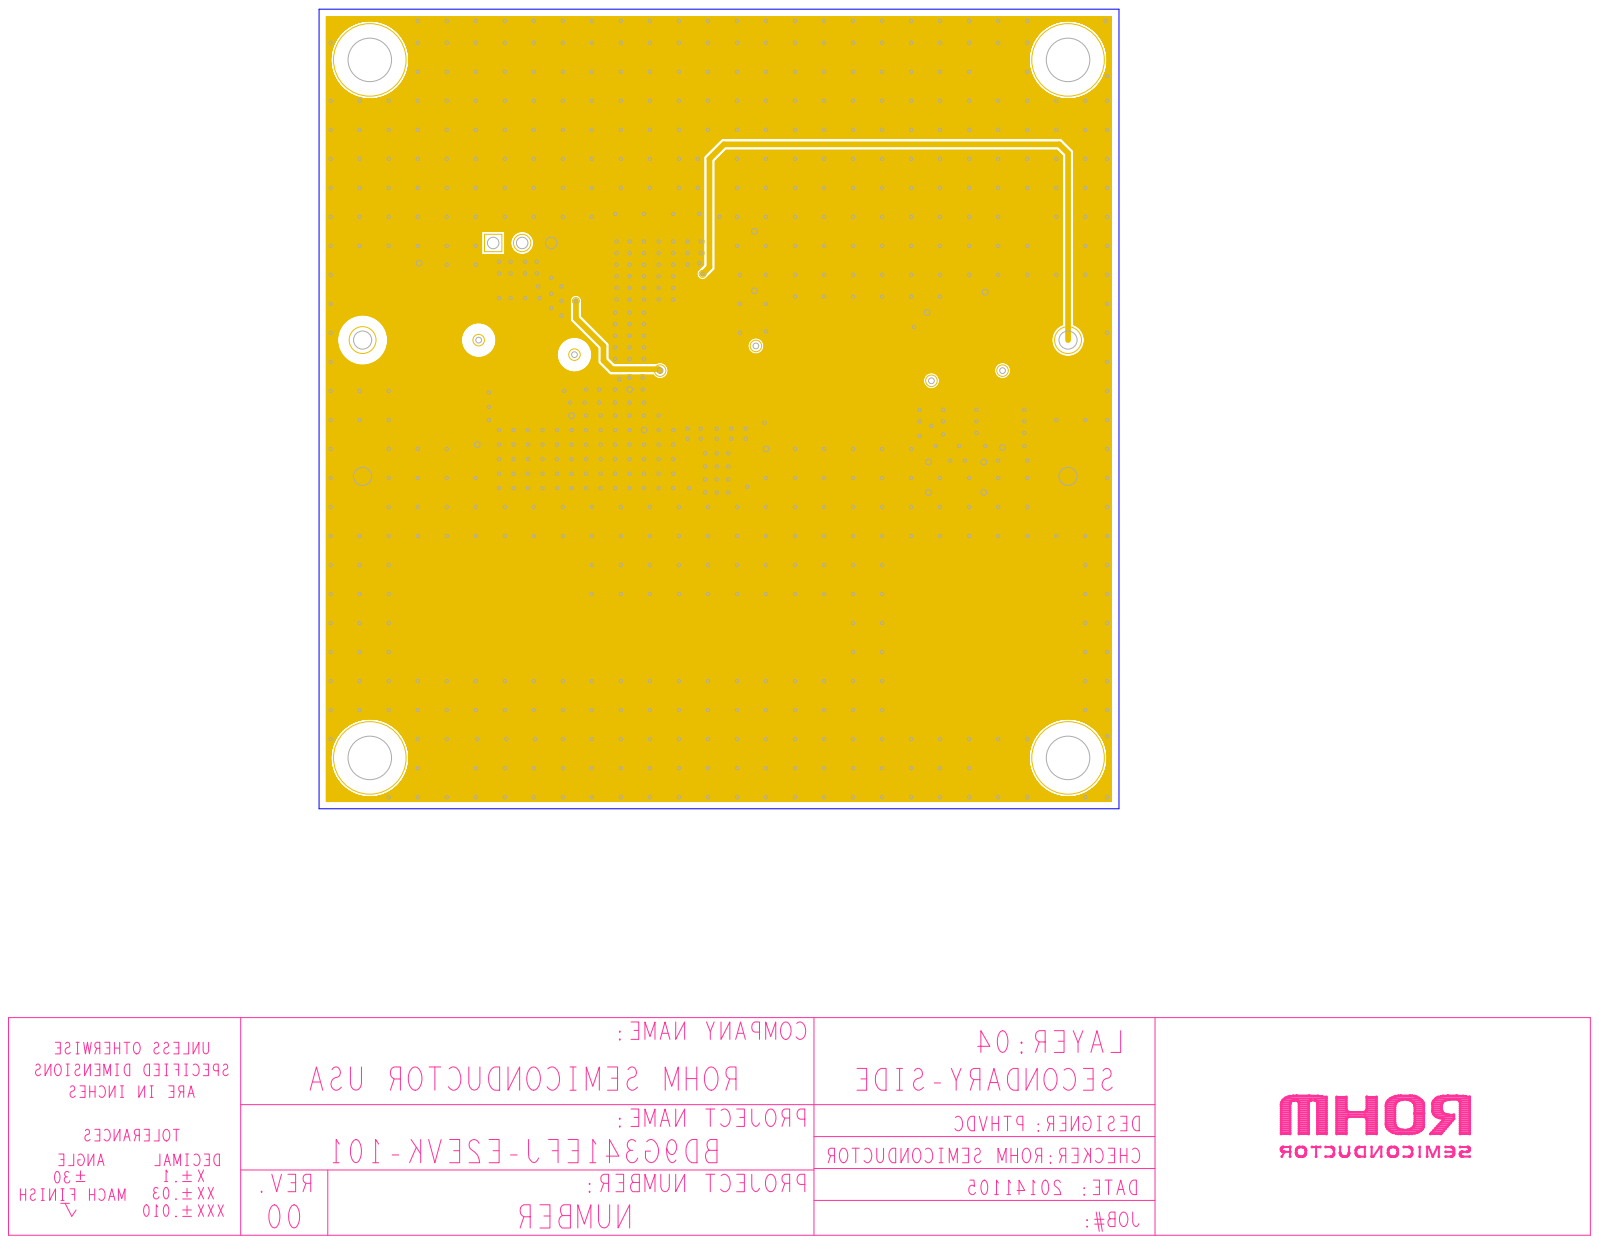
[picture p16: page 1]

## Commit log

2015-09-30 Initial Commit
    Added ReadMe, Application Note, Design Files, and Measurement Reports
    [BD9G341EFJ-E2EVK-101_BOM_REV01_2014-10-17.xlsx, BD9G341EFJ-E2EVK-101_BRD_REV00_2014-11-05.brd, BD9G341EFJ-E2EVK-101_SCH_REV01_2014-10-17.DSN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]
2015-12-17 Create automatic component selection guide
    Highlight
    • RT setting for switching frequency
    • Maximum On-Time for maximum output capability
    • UVLO and hysteresis which may conflict with output settings by the
    resistor feedback network.
    [BD9G341_Automatic_Component_Selection_Guide.xlsx]
2015-12-18 Update component selection guide
    Highlight components
    [BD9G341_Automatic_Component_Selection_Guide.xlsx]
2016-09-27 Updated with RoHS Compliance Information
    Added RoHS References for FAB-ASSY Process
    [BD9G341EFJ-E2EVK-101_BOM_REV01_2014-10-17.xlsx]
